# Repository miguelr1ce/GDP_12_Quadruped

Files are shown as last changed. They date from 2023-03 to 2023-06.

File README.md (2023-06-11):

# GDP_12_Quadruped
4th year group project for University of Southampton (2022/2023)

Title: Creating a Modular Quadrupedal Robot

Group Members:
1) Ryan Khoo Yeap Hong                     -> Lead Vibe Checker
2) Nirvair Kaur Jasbir Singh               -> Editor & Chief
3) Khor Chong Shen                         -> ODrive Whisperer
4) Miguel Antonio Alfonso Villarivera      -> The Cogfather
5) Jia Hao Gau                             -> Mr. Safety
6) Ka Wai Ken Chung                        -> Gait Keeper
 
 FULL FUSION360 CAD FILE: https://drive.google.com/file/d/1EFiVYnqyQNYSkIoPCi1z3-Mt8qbjOBQe/view?usp=sharing
 
 (open fusion and import file, will populate with all designs and dependencies)
 
 Some features of our quadrupedal robot
 1. 3DoF for each leg
 2. Modular leg detach, feet, body mounts
 3. Herringbone and worm wheel gear reduction
 4. Gait Generating GUI
 5. Bluetooth Controller
 
Mqrph

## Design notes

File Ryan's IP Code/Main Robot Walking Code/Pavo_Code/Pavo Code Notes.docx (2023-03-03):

# Pavo robot-side Code Information

Content of code OUTDATED:

1. Changeable and tuneable parameters
  - General actiaon execution speed
  - Empty footstep modifier
  - Start-up options (toggles initialisation or testing mode)
- Calibration for centres of servos
- Movement ranges, maximum degrees of movement for each joint
2. Movement sets
3. Not usually changed parameters and various other variable definitions
  - Servo Numbers
4. Predefined Functions and calculations
  - Servodriver Pulse calculations
  - executePosition function, Write position dataset to servos
5. assumePosition()
  - Misc setup
6. Setup
  - Serial begin at 9600 baudrate
  - Servodriver setup
7. Void Loop
  - check controller command data
  - Manual Pitch Control

## Walking set info

Final set to be written to servos is a combination of an empty set of sets, and the front back movements and left right movements are appended on to a degree determined by the fuzzy logic crisp output.

0.8 secs looks to be a good duration for a full walk cycle as of now

How do I make between different sets have different amount of divisions?

Divisions will occur at even intervals, so if I want a faster movement, I will divide a movement into fewer divisions that end up more spaced out

Sets in sets

If modifiers for x and y are below a certain preset threshold, pavo will resume neutral standing positin unmovingi.e. Pavo will automatically come to rest if it is balanced

Easing function Multipliers:

Linear:

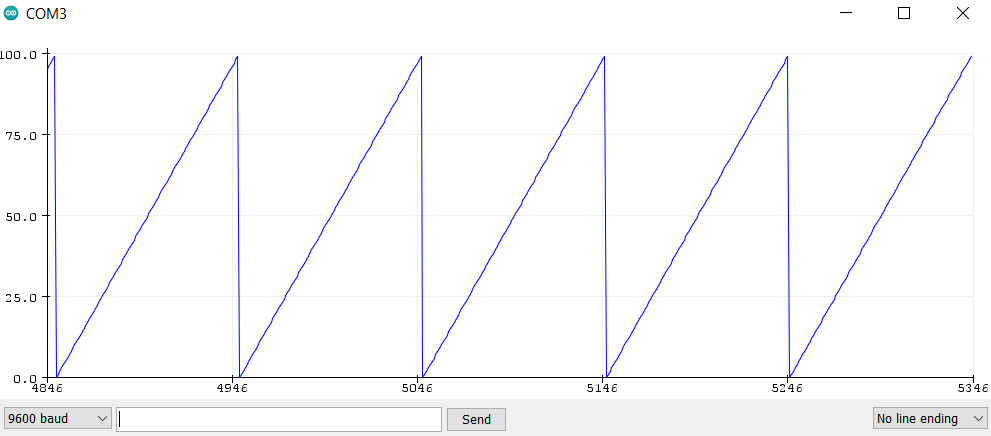
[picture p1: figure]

slow down:

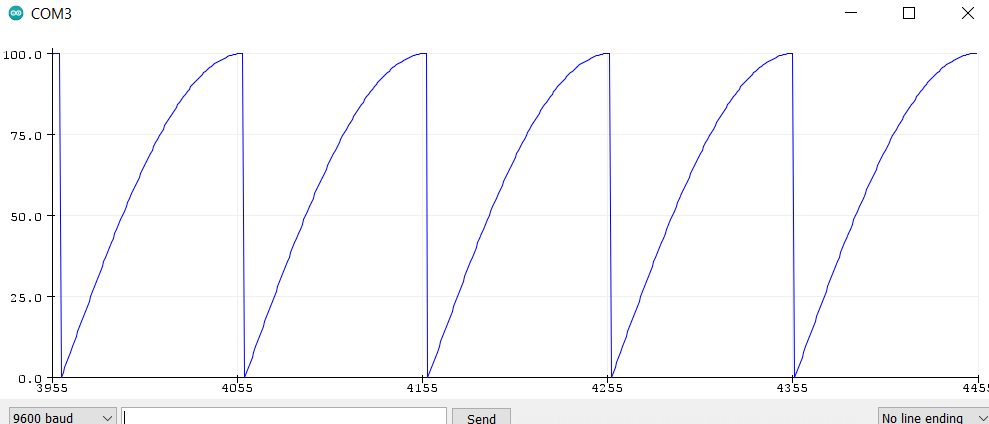
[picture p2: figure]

speed up:

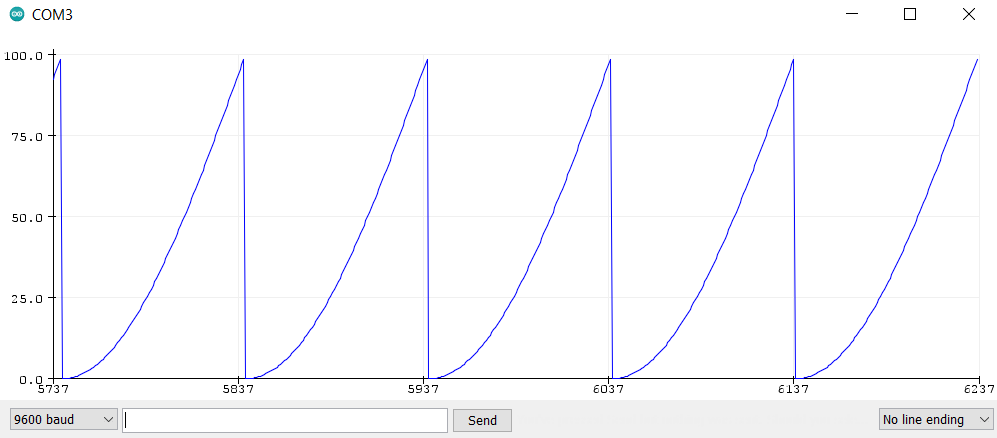
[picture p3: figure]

MEMORY MAXIMUM HAS BEEN REACHED

Due to the large size of sets that need to be processed and stored for footstep planning, the maximum divisions has been set to 18

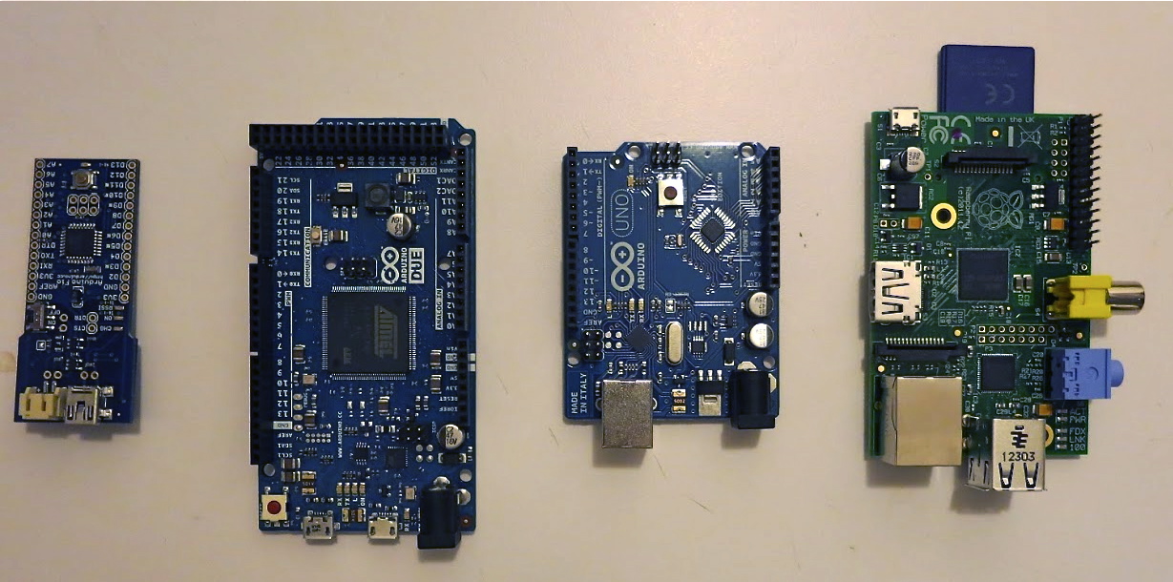
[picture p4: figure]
Arduino Uno and Due Size Comparison (with Raspberry Pi and Fio, too) — DO IT: Projects, Plans, and How-tos

The Due is not too much bigger

https://learn.adafruit.com/memories-of-an-arduino/optimizing-sram

Cycle Loop:

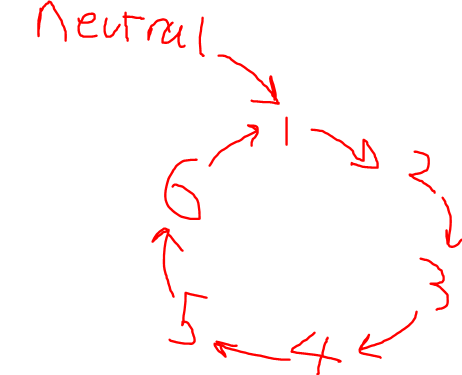
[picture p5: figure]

Old walking sets

//Temporary walking sets L L L R R R M M M t ---------------------------------------------------------------------

const int temp1ServoState[] = {-30, -10, 0, 80, 100, 0, 0, 0, 0, 15};

const int temp2ServoState[] = {-15, 30, 0, 10, 80, 0, 0, 0, 0, 15};

const int temp3ServoState[] = {-80, 40, 0, 10, 40, 0, 0, 0, 0, 15};

const int temp4ServoState[] = {-80, -100, 0, 30, 10, 0, 0, 0, 0, 15};

const int temp5ServoState[] = {-10, -80, 0, 15, -30, 0, 0, 0, 0, 15};

const int temp6ServoState[] = {-10, -40, 0, 80, -40, 0, 0, 0, 0, 15};

Exponential filter:

https://www.megunolink.com/documentation/arduino-libraries/exponential-filter/

explain the math ryan.

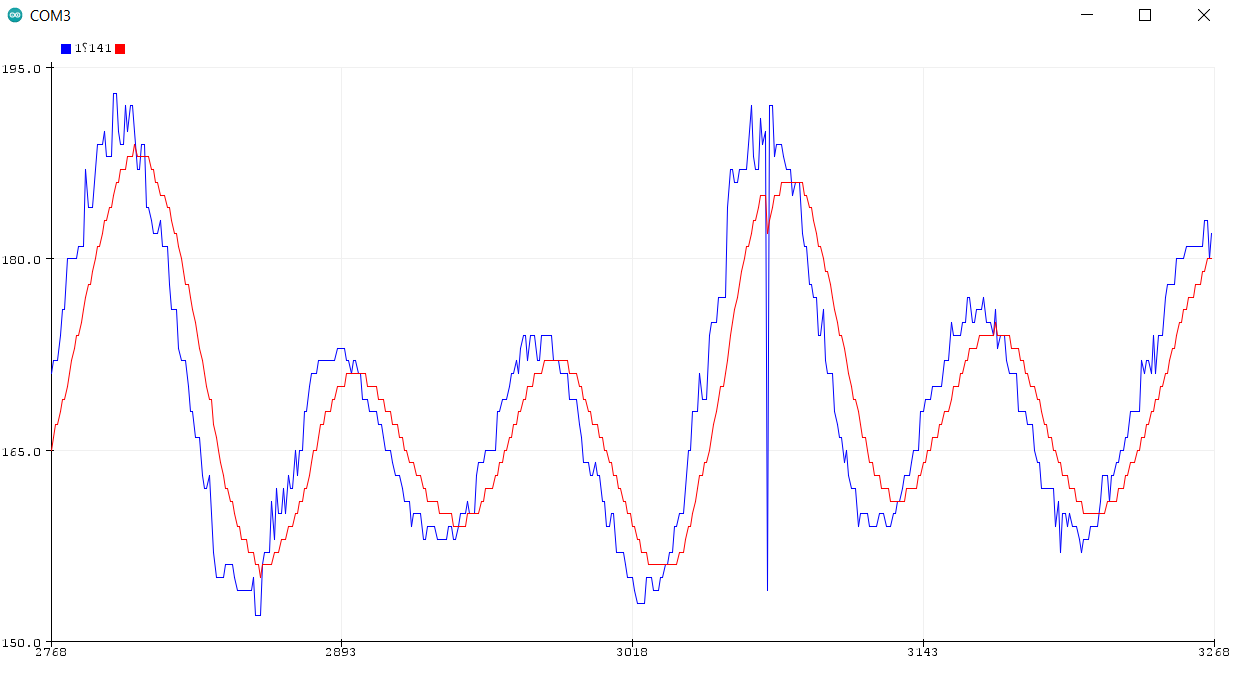
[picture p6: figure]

Calculate pitch and yaw n stuff from IMU

https://howtomechatronics.com/tutorials/arduino/arduino-and-mpu6050-accelerometer-and-gyroscope-tutorial/

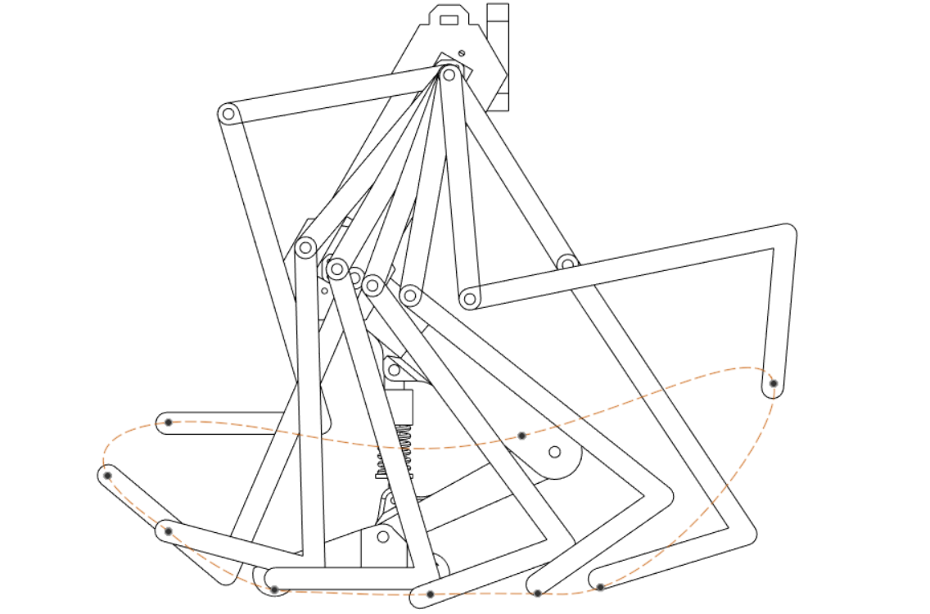
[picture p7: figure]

“air”

“air”

Contact 1 C2 C3 C4 C5 C6

6 stages are touching ground, 2 are in the air to facilitate the swing forward. The other leg follows the same cycle but is offset by 4 stages, allowing 2 states of ground contact to overlap, fulfilling the double contact state for a total of 26% of the cycle as in figure [bird walk]. It can be broken down into 6 states of ground contact and 2 states of mid-air swing, this is similar for the sideways movement, but is simpler, as the ground contact only requires the moving of the hip servos sideways at a regular speed until the swing phase that swings the leg back to a starting position.

The duration of ther stages can be altered in the code with the time variable attached to each of the sets, but with a single gait cycle broken down into 8 parts, each part comes to 100/8=1205% which is in line with the 13% recorded, this allows a low number of divisions with all the sets having the same duration.

If higher ram with more divisions possible, the time variable can be adjusted to allow the double support phases to come closer to 13% of the cycle.

This is a

https://edmond.mpdl.mpg.de/dataset.xhtml?persistentId=doi:10.17617/3.ETFG41

# PROGMEM implementation

Using https://github.com/Chris--A/PGMWrap to aid in storing sets in flash memory instead of SRAM to free up space:

Before implementation:

After:

Allows max divisions to go back up to above 10, allowing for smooth motion and the easing function to actually do things!!!

After this limiting factor is speed of loop execution, as of implementing the PROGMEM, a loop takes on average 0.011 seconds

# Leg planning puppeteering

Empty set was made representing the foot lift, and side to side swing manually tuned to reduce the hip wobbling, counteracting the legs causing the hip to swing back and forth

Footstep cycle: | % cycle | Empty | Front/back | Left/right
1 | 12.5% | Right leg up + spine counteract | L C3, R air | L C3, R air
1-2 | | - | R Swing + L walk | R Swing + L walk
2 | 12.5% | Right leg up + spine counteract | L C4, R air | L C4, R air
2-3 | | Right leg move down | L walk | L walk
3 | 12.5% | Neutral | L C5, R C1 | L C5, R C1
3-4 | | - | L and R walk, D support. | L and R walk, D support.
4 | 12.5% | Neutral | L C6, R C2 | L C6, R C2
4-5 | | Left leg move up | R walk | R walk
5 | 12.5% | Left leg up + spine counteract | L air, R C3 | L air, R C3
5-6 | | - | L Swing + R walk | L Swing + R walk
6 | 12.5% | Left leg up + spine counteract | L air, R C4 | L air, R C4
6-7 | | Left leg move down | R walk | R walk
7 | 12.5% | Neutral | L C1, R C5 | L C1, R C5
7-8 | | - | L + R walk, D support. | L + R walk, D support.
8 | 12.5% | Neutral | L C2, R C6 | L C2, R C6
8-1 | | Right leg move up | L walk | L walk

Departure from biomimicry,

Due to the low strength of the servos, the gait angles need to be smaller for the servos to be able to actuate to the target positions, and alos due to this reduced dynamic forces, the robot is unable to properly achive foot lift off during its swing phase, essentially maintaining double support throughout its entire gait cycle. With the servos implemented, it is able to shuffle along, but not fully walk like the cycle illustrates, despite while simply increasing the actuation modifiers, such as the angle of gait swings and sufficiently powerful servos would allow for walking as in the above diagram.

This shuffling is due the the compliance of the frame and joints of the robot, when a foot is raised, instead of the foot rising, the entire body will bend to accommodate this new positioning, this compliance is due to the weight of the hip and spine pressing down on the leg assemblies. This causes the overall robot to bend in ways tha3t would not be possible if all parts were rigid. This issue may be alleviated by increasing the motion of the joints, where the body is rigid enough to not allow angular compliance of larger angles, however, the servos are simply not strong enough achieve the torques necessary to perform these larger angled foot steps, regardless of sideways or forwards.

It is the combination of these two issues that limit each other that result in the robot not performing as initially intended. However, knowing this, work was still done to maximise the robot’s ability to maneuver under these new sets of constraints.

In light of this, modifications were made to improve performance in its current form (utilising constant double support. The percentage of time the legs are swinging back forward (supposedly mid-air under normal circumstances) have been reduced to half that of the other stages. With all other parameters the same, this increased walking speed by.

RYAN test to do: original planned motion based on real quail; improvements based on research platform.

SERVOS NOT STRONG ENOUGH TO WALK, CAN SHUFFLE THOUGH

The current movements are broken down into 3 sets that are combined with different weightages, future work may also use this now ealisy expandable framework to break down complex movement into further sub-catagories to further refine and improve control of the CPG. An example would be breaking down the empty set into separate footstep and counterbalance movements, and have the counterbalance be further informed by more IMU data to counteract more dynamic, unexpected perturbances such as potholes, inclined/slippery surfaces, etc.

This system that relies on higher functionality instead of taking into account all the math behind the dynamics, inverse kinematics, etc. not only saves computation but is also much more readily adaptable to new more challenging terrain, where a system whose movements are calculated based on assumptions such as 0-inclined surfaces, no slip, unrealistic perfectly rigid body parts may need to overhaul its entire calculations to take these new variables into account, this system may be altered by simply changing parameters or breaking down the step cycles into more parts as mentioned above.

Demonstration values, slow exaggerated movements.

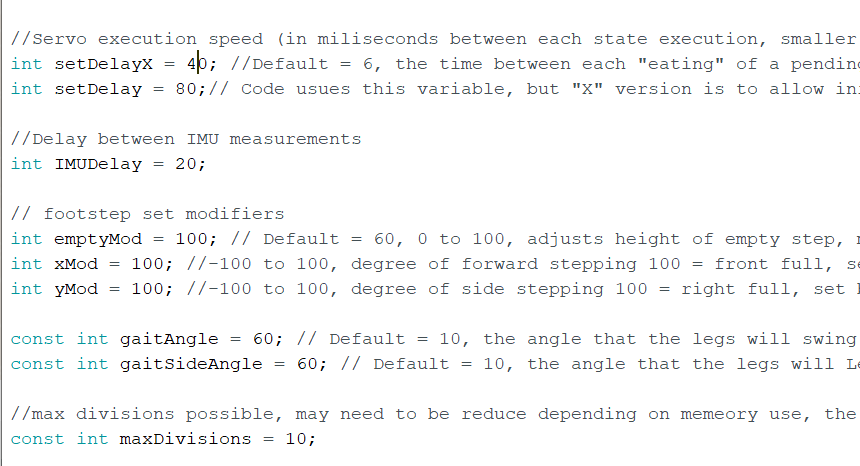
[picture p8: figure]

{50, 24, -20, 0, -64, -94, 5, 0, 14, 10}

Servo 8

Servo 7

Servo 4

Servo 5

Servo 2

Divisions

Servo 9

Servo 6

Servo 3

Servo 1

9

9

9

9

Gait Cycle Stages

Rest state

1

2

3

8

4

9

# Archived debugging code:

// //print pending set

// Serial.println("Pending set:");

// for ( int i = 0; i < maxDivisions+1 ; i++){

// Serial.print("Set indexed at ");

// Serial.print(i);

// Serial.print(": {");

// for ( int s = 0; s < 9 ; s++){

// Serial.print(pendingSet[i][s]);

// Serial.print(", ");

// }

// Serial.println("}");

// }

Goes just before end of respective servo loop in assumePosition():

// //printing temporary column

// Serial.print("tempcolumn[]");

// Serial.print(" for servo number ");

// Serial.print(servoNumber);

// Serial.print(": {");

// for ( int i = 0; i < divisions ; i++){

// Serial.print(tempColumn[i]);

// Serial.print(", ");

// }

// Serial.println("}");

// Serial.print("servo ");

// Serial.print(servoNumber);

// Serial.println("'s transition values calculated");

Goes below respective servo loop in assume position function

//// Printing transitionArray

//Serial.println("Transition array:");

//for (int s=0;s<9;s++){

// Serial.print("colunm array for servo ");

// Serial.print(s);

// Serial.print(": [");

// for (int i = 0; i < divisions ; i++){

// Serial.print(transitionArray[s][i]);

// Serial.print(", ");

// }

// Serial.println("] ");

//}

// //print out new set

// Serial.print("Old set overwritten to new set: ");

// for (int i=0; i<9; i++){

// Serial.print(newSet[i]);

// Serial.print(", ");

// }

// Serial.println(" ");

//Write transitionary array into the pending sets from the back

//Serial.println("Populating pending set:");

//write to pending sets from transition array, transposing matrix

for ( int i = 0; i < divisions ; i++){

for ( int s = 0; s < 9 ; s++){

pendingSet[divisions-i-1][s] = transitionArray[s][i];

//Serial.println(pendingSet[divisions-i-1][s]);

}

//Serial.print("one pending set added at index: ");

//Serial.println(divisions-i-1);

}

Nomenclature:

m | - | Mass
t | - | Time

Set value:

20

0

100

-100

True Servo angle:

159°

109°

134°

139°

Servo Centre - range

Servo Centre + range

Servo Centre

(Centre pre-set at 134°, allowable range pre-set at ±25°)

{{x, x, x, x, x, x, x, x, x, 0},

{x, x, x, x, x, x, x, x, x, 0},

{x, x, x, x, x, x, x, x, x, 0},

{x, x, x, x, x, x, x, x, x, 0},

{x, x, x, x, x, x, x, x, x, 0},

{x, x, x, x, x, x, x, x, x, 0},

{x, x, x, x, x, x, x, x, x, 0},

{x, x, x, x, x, x, x, x, x, 0},

{x, x, x, x, x, x, x, x, x, 0},

⋮

{x, x, x, x, x, x, x, x, x, 0},

⋮

{0, 0, 0, 0, 0, 0, 0, 0, 0, N}}

New position set

Transitionary position sets

Length dependant on maximum divisions allowed by pre-set variable in code

Current position set

Last set containing only “available sets” variable

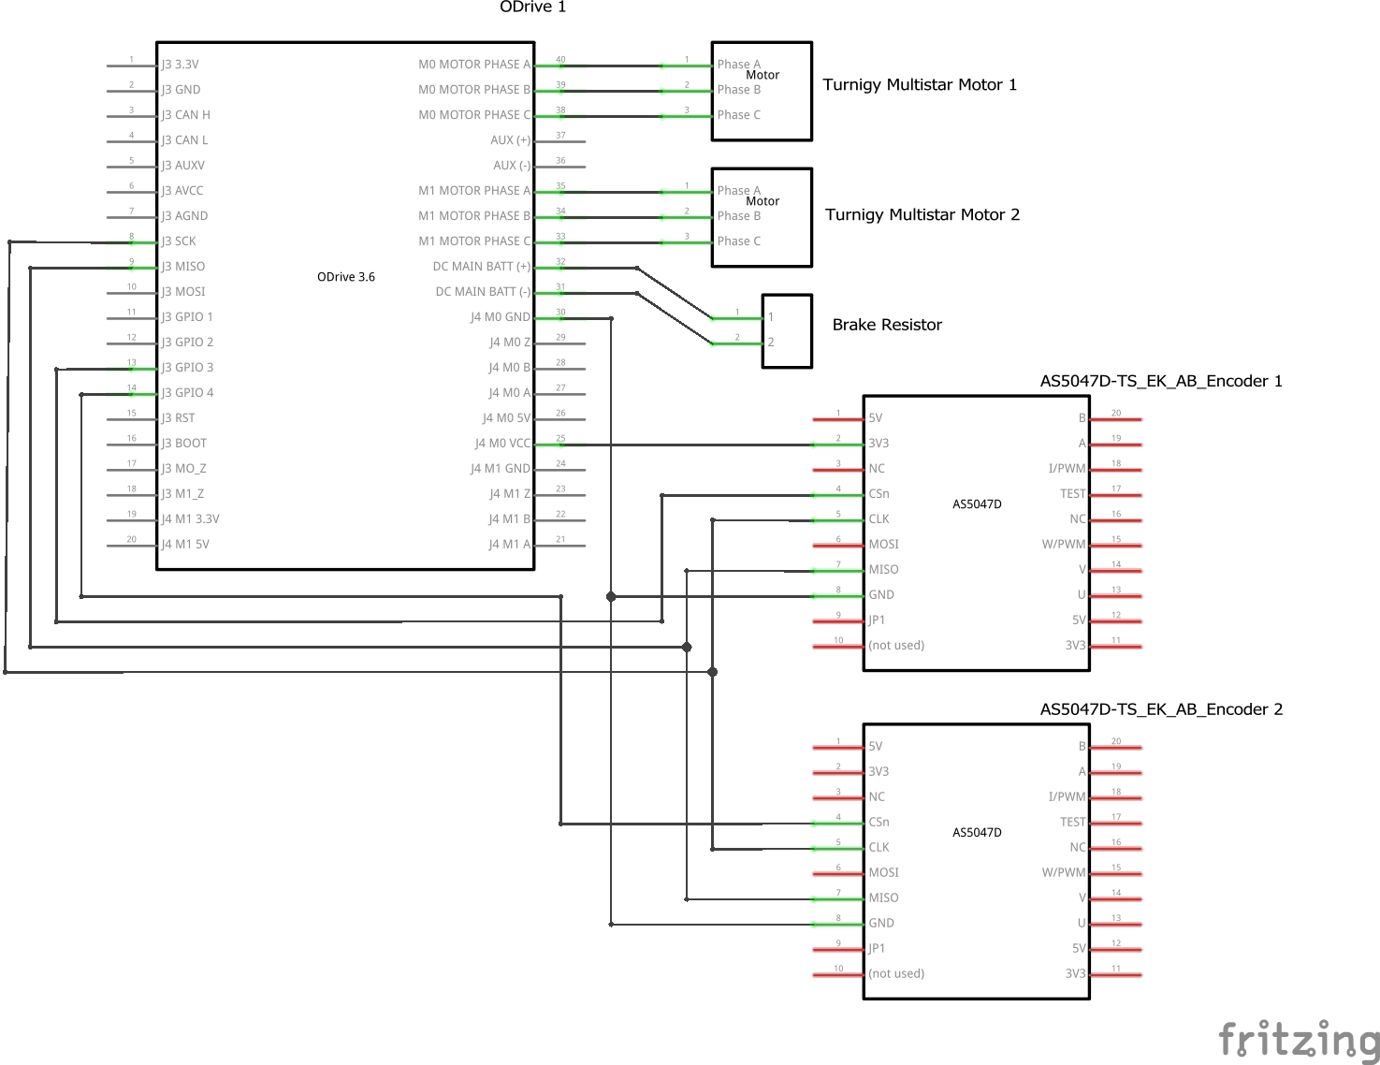
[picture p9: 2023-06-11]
Morph Designs/Circuit Diagrams/motor+encoder_schem.jpg

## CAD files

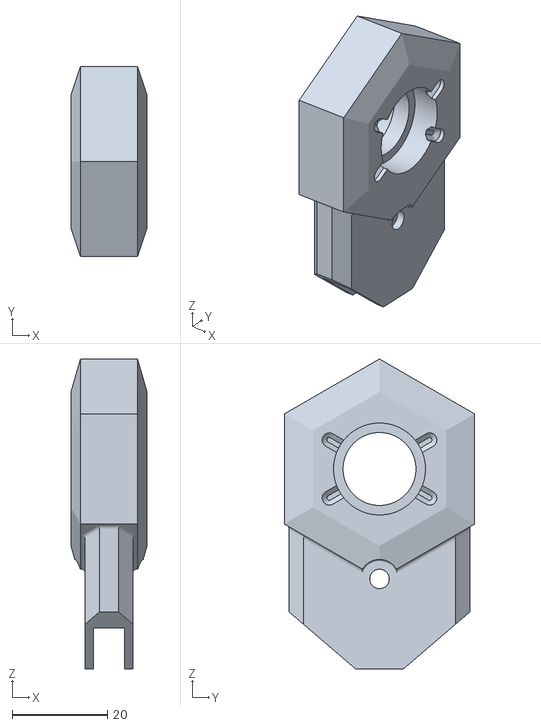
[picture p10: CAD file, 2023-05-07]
Morph Designs/Knee Joint/Main Knee Joint.stl
16.0 x 40.0 x 65.1

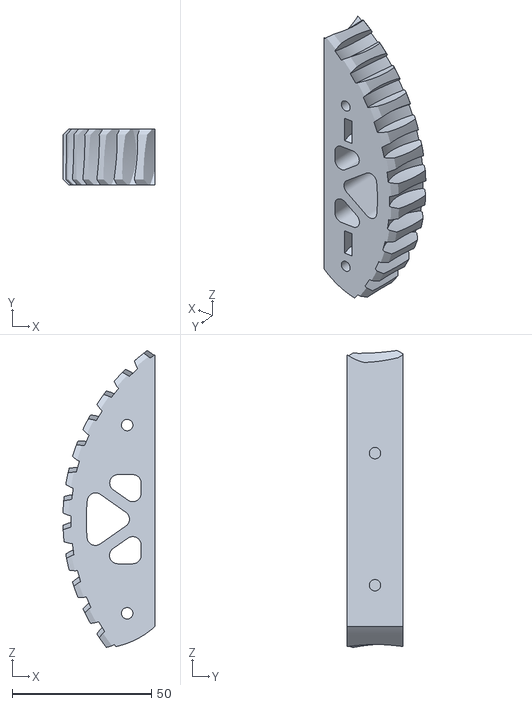
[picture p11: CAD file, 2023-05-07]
Morph Designs/Worm Gear assembly/Worm Wheel Main.stl
33.0 x 20.0 x 106.6

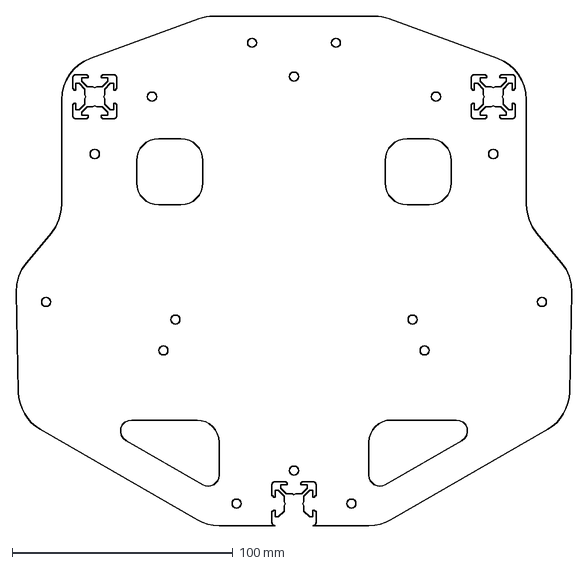
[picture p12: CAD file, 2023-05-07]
Morph Designs/Body/2X Middle Plate.dxf
252.0 x 230.9 mm

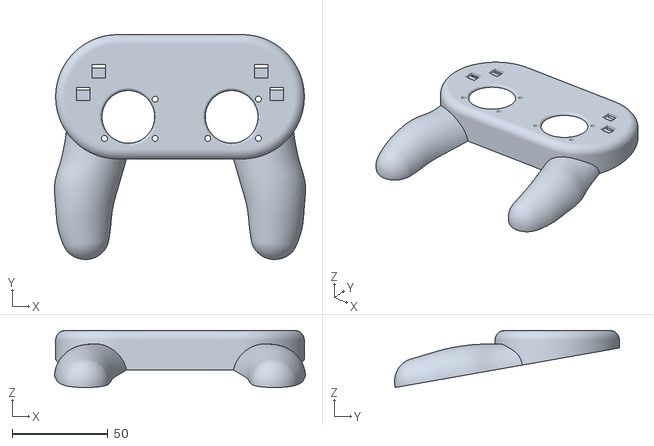
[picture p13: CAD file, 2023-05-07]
Morph Designs/Controller/Top Body.stl
131.2 x 117.5 x 29.8

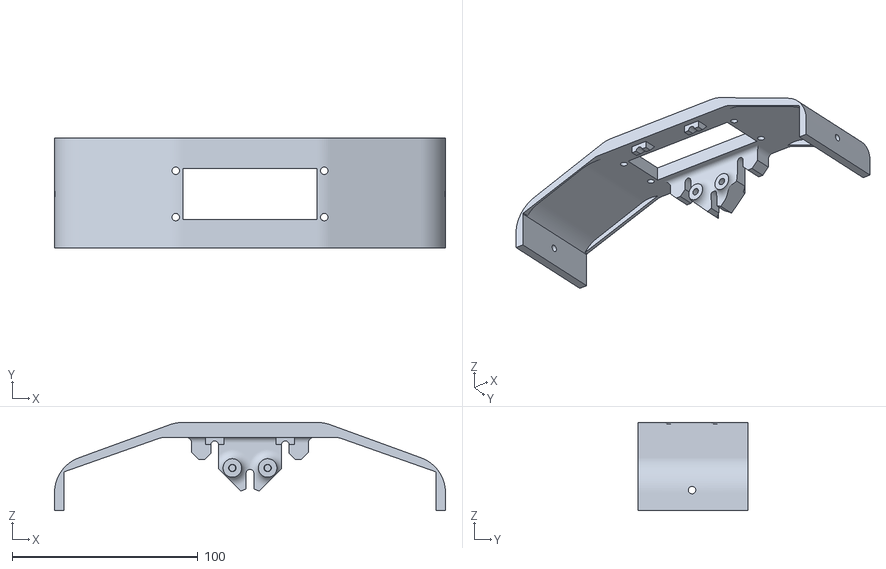
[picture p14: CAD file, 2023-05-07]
Morph Designs/Electronics housing/Electronics Housings v7.stl
210.6 x 59.2 x 47.5

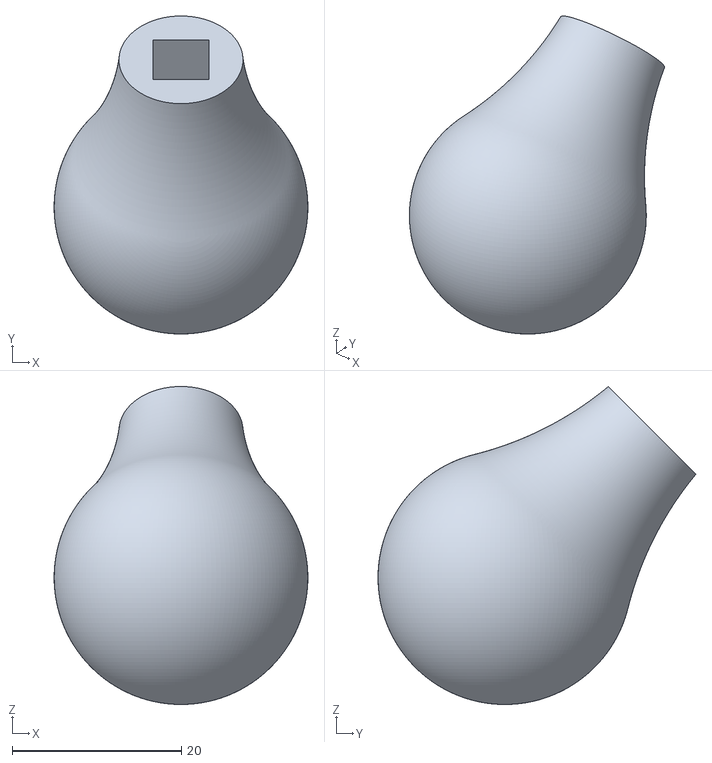
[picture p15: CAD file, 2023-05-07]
Morph Designs/Feet/Round Foot V2.stl
30.0 x 37.6 x 37.6

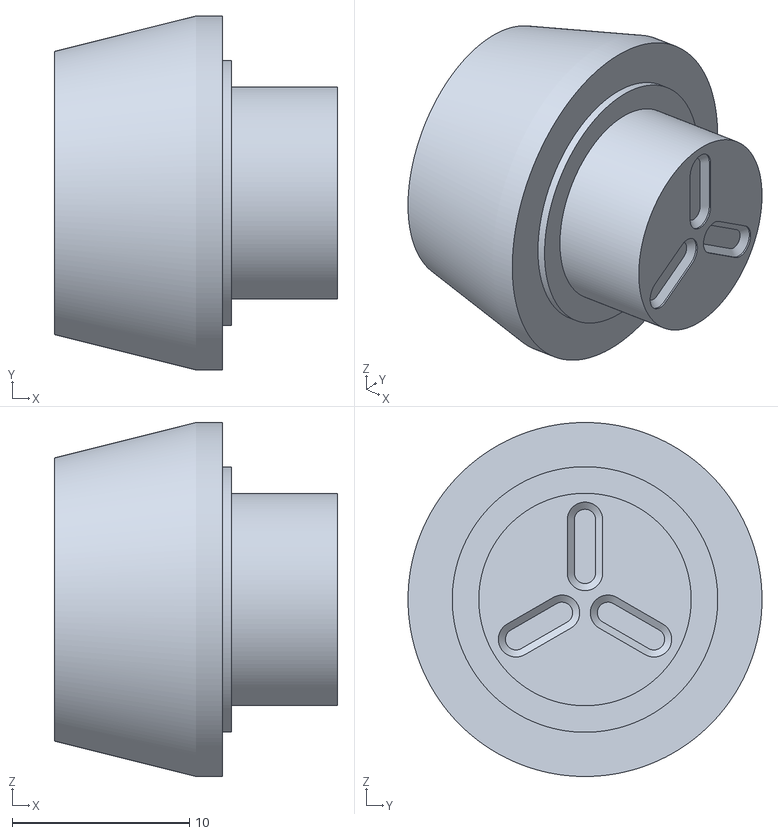
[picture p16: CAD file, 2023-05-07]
Morph Designs/Gear Assembly/Shaft Brace B.stl
16.0 x 20.0 x 20.0

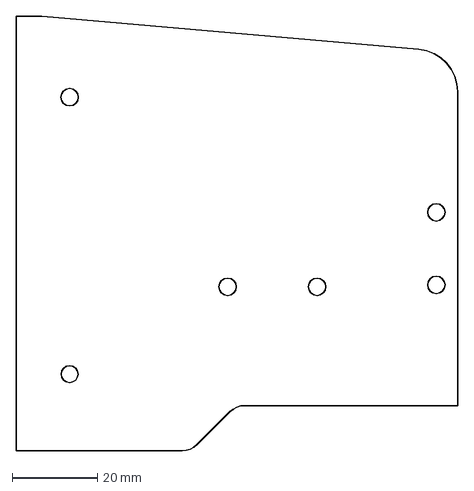
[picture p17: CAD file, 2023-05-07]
Morph Designs/Gear Box Assembly/Side Panel B.dxf
103.6 x 102.0 mm

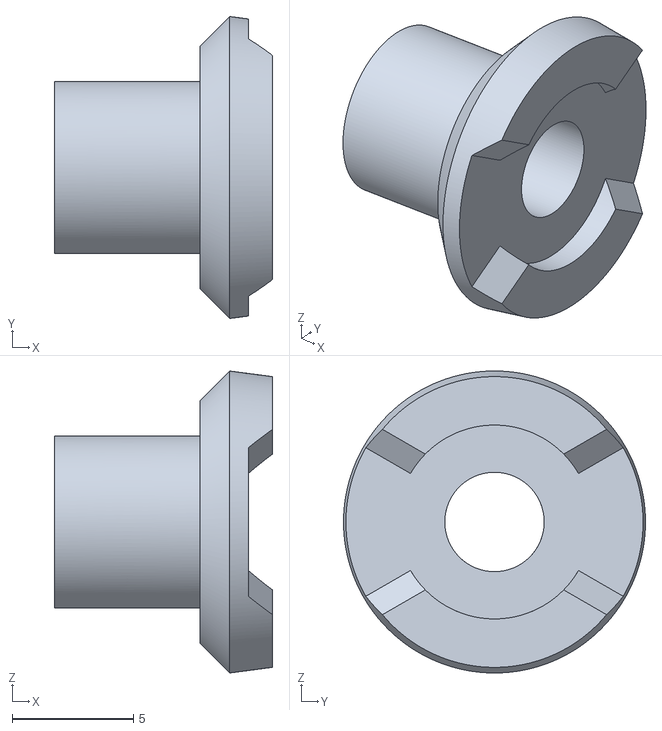
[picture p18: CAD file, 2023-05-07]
Morph Designs/Knee Joint/Gear Holder Outer.stl
9.00 x 12.5 x 12.5

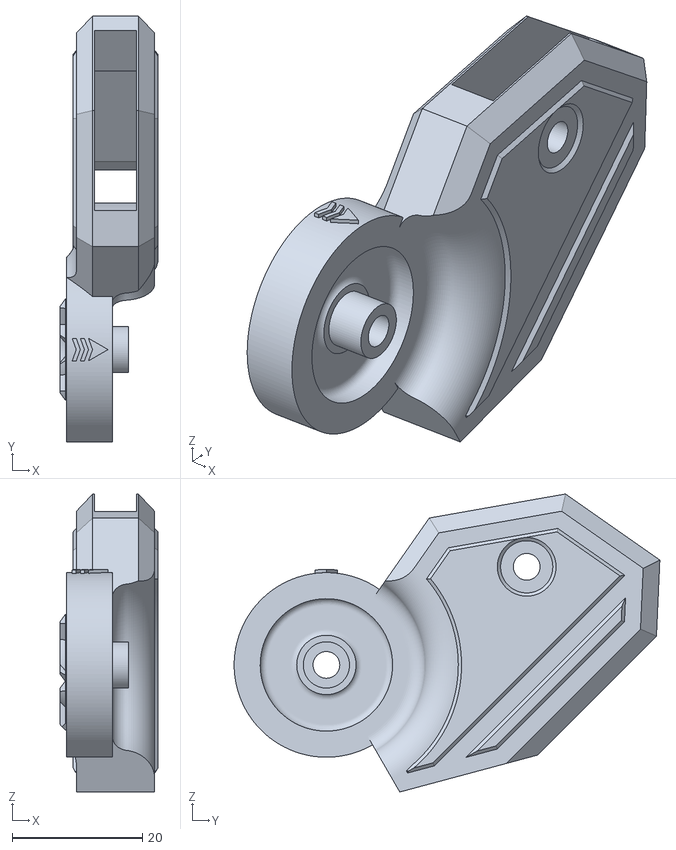
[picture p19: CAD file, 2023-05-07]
Morph Designs/Legs/Foot Joint 2.stl
15.0 x 65.3 x 45.7

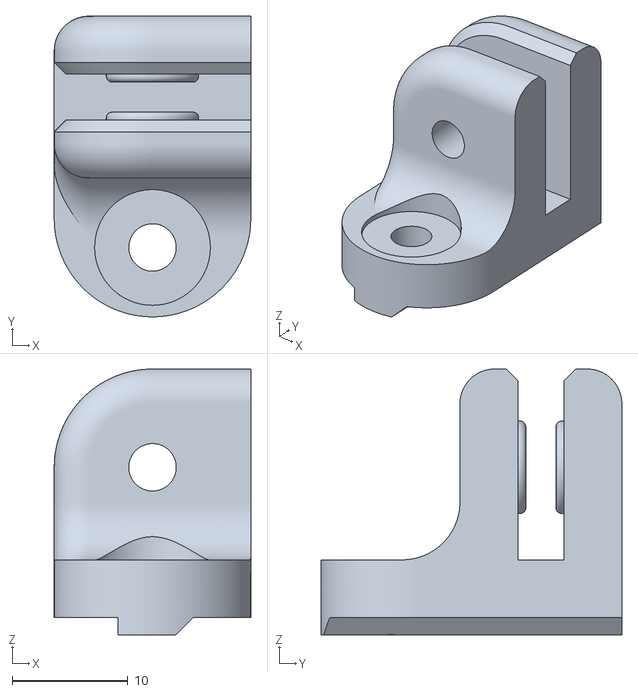
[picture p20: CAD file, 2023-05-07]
Morph Designs/Odrive Mounts/Odrive Mount V4.stl
17.0 x 26.0 x 23.0

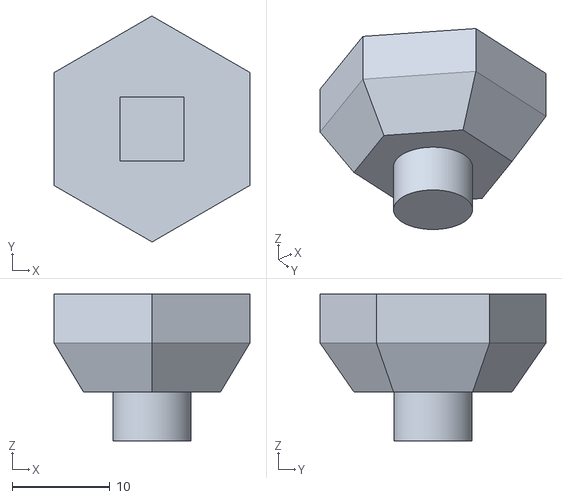
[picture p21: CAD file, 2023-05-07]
Morph Designs/Worm Gear assembly/Motor Shaft Brace'.stl
20.0 x 23.1 x 15.0

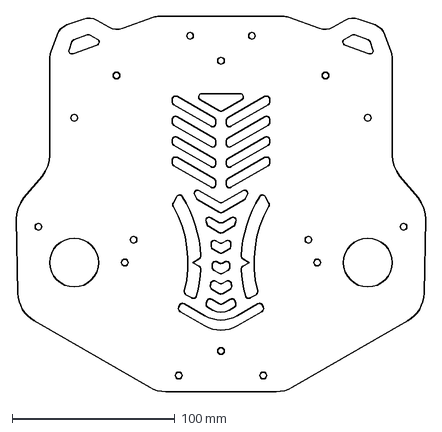
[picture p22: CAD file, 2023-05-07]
Morph Designs/Body/Face Plate Blank.dxf
252.0 x 230.9 mm

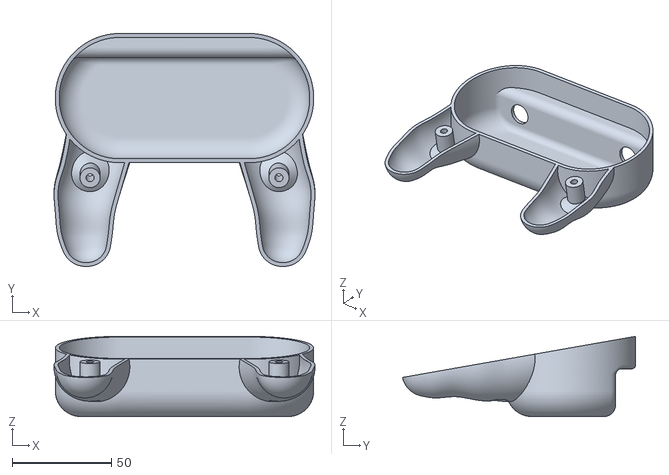
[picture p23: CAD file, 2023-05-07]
Morph Designs/Controller/Bottom.stl
131.3 x 117.2 x 40.4

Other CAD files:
Morph Designs/Electronics housing/Electronics board DXF.dxf
Morph Designs/Gear Assembly/2X Shaft Brace Bearing Mount.stl
Morph Designs/Gear Box Assembly/Back panel.dxf
Morph Designs/Knee Joint/Gear Holder Inner.stl
Morph Designs/Body/Aluminium Extrusion Braket.stl
Morph Designs/Body/Face Plate Logos.dxf
Morph Designs/Gear Assembly/Big Gear.stl
Morph Designs/Gear Assembly/Gear Spacer A V2.stl
Morph Designs/Gear Assembly/Gear Spacer B1.stl
Morph Designs/Gear Assembly/Gear Spacer B2.stl
Morph Designs/Gear Assembly/Gear Spacer C.stl
Morph Designs/Gear Assembly/Motor Shaft Mount A.stl
Morph Designs/Gear Assembly/Motor Shaft Mount B.stl
Morph Designs/Gear Assembly/Shaft Brace A.stl
Morph Designs/Gear Box Assembly/Acrylic Mount.stl
Morph Designs/Gear Box Assembly/Acrylic plate.dxf
Morph Designs/Gear Box Assembly/Bearing Clasp Top.stl
Morph Designs/Gear Box Assembly/Bearing clasp Bottom.stl
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

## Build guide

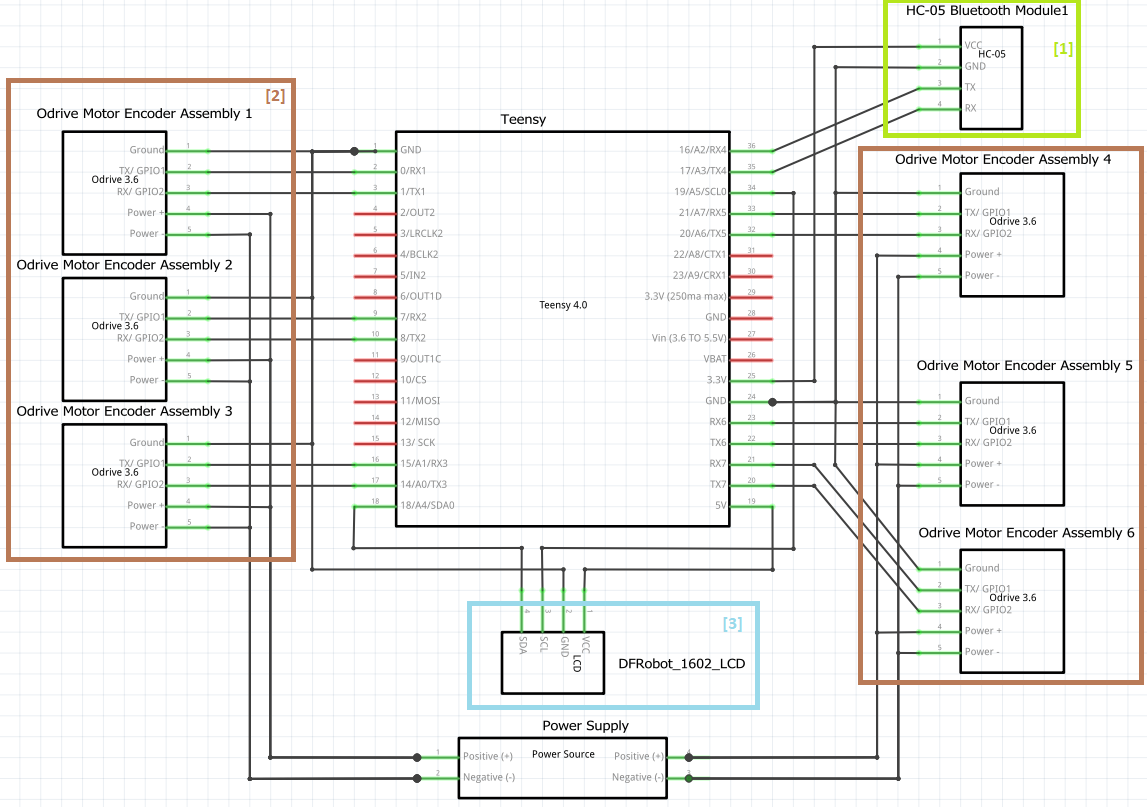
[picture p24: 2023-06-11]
Morph Designs/Circuit Diagrams/Teensy_assembly.png

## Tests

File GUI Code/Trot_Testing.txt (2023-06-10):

struct Trot_Testing{
    double March[itr][legn][coor]={{{0, 0, 0.0}, {0, 0, 0.0}, {0, 0, 0.0}, {0, 0, 0.0}}, {{0, 0, 50.0}, {0, 0, 50.0}, {0, 0, 0.0}, {0, 0, 0.0}}, {{0, 0, 50.0}, {0, 0, 50.0}, {0, 0, 0.0}, {0, 0, 0.0}}, {{0, 0, 50.0}, {0, 0, 50.0}, {0, 0, 0.0}, {0, 0, 0.0}}, {{0, 0, 0.0}, {0, 0, 0.0}, {0, 0, 0.0}, {0, 0, 0.0}}, {{0, 0, 0.0}, {0, 0, 0.0}, {0, 0, 50.0}, {0, 0, 50.0}}, {{0, 0, 0.0}, {0, 0, 0.0}, {0, 0, 50.0}, {0, 0, 50.0}}, {{0, 0, 0.0}, {0, 0, 0.0}, {0, 0, 50.0}, {0, 0, 50.0}}};
    double FB[itr][legn][coor]={{{0, -60.0, 0}, {0, -60.0, 0}, {0, 60.0, 0}, {0, 60.0, 0}}, {{0, -30.0, 0}, {0, -30.0, 0}, {0, 30.0, 0}, {0, 30.0, 0}}, {{0, 0.0, 0}, {0, 0.0, 0}, {0, 0.0, 0}, {0, 0.0, 0}}, {{0, 30.0, 0}, {0, 30.0, 0}, {0, -30.0, 0}, {0, -30.0, 0}}, {{0, 60.0, 0}, {0, 60.0, 0}, {0, -60.0, 0}, {0, -60.0, 0}}, {{0, 30.0, 0}, {0, 30.0, 0}, {0, -30.0, 0}, {0, -30.0, 0}}, {{0, 0.0, 0}, {0, 0.0, 0}, {0, 0.0, 0}, {0, 0.0, 0}}, {{0, -30.0, 0}, {0, -30.0, 0}, {0, 30.0, 0}, {0, 30.0, 0}}};
    double LR[itr][legn][coor]={{{-60.0, 0, 0}, {-60.0, 0, 0}, {60.0, 0, 0}, {60.0, 0, 0}}, {{-30.0, 0, 0}, {-30.0, 0, 0}, {30.0, 0, 0}, {30.0, 0, 0}}, {{0.0, 0, 0}, {0.0, 0, 0}, {0.0, 0, 0}, {0.0, 0, 0}}, {{30.0, 0, 0}, {30.0, 0, 0}, {-30.0, 0, 0}, {-30.0, 0, 0}}, {{60.0, 0, 0}, {60.0, 0, 0}, {-60.0, 0, 0}, {-60.0, 0, 0}}, {{30.0, 0, 0}, {30.0, 0, 0}, {-30.0, 0, 0}, {-30.0, 0, 0}}, {{0.0, 0, 0}, {0.0, 0, 0}, {0.0, 0, 0}, {0.0, 0, 0}}, {{-30.0, 0, 0}, {-30.0, 0, 0}, {30.0, 0, 0}, {30.0, 0, 0}}};
    double RT[itr][legn][coor]={{{-30.51, 18.68, 0}, {30.51, -18.68, 0}, {26.8, 23.69, 0}, {-26.8, -23.69, 0}}, {{-14.84, 10.01, 0}, {14.84, -10.01, 0}, {13.92, 11.26, 0}, {-13.92, -11.26, 0}}, {{0.0, 0.0, 0}, {0.0, 0.0, 0}, {0.0, 0.0, 0}, {0.0, 0.0, 0}}, {{13.92, -11.26, 0}, {-13.92, 11.26, 0}, {-14.84, -10.01, 0}, {14.84, 10.01, 0}}, {{26.8, -23.69, 0}, {-26.8, 23.69, 0}, {-30.51, -18.68, 0}, {30.51, 18.68, 0}}, {{13.92, -11.26, 0}, {-13.92, 11.26, 0}, {-14.84, -10.01, 0}, {14.84, 10.01, 0}}, {{0.0, 0.0, 0}, {0.0, 0.0, 0}, {0.0, 0.0, 0}, {0.0, 0.0, 0}}, {{-14.84, 10.01, 0}, {14.84, -10.01, 0}, {13.92, 11.26, 0}, {-13.92, -11.26, 0}}};
};

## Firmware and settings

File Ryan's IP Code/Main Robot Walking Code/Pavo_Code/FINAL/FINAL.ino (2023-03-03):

// Ryan Khoo Yeap Hong | 30480183 | Year 3 Individual Project | Academic year 2021/2022
#include <Wire.h>
#include <Adafruit_PWMServoDriver.h>
Adafruit_PWMServoDriver pwm = Adafruit_PWMServoDriver();
#include <Adafruit_ICM20948.h>
Adafruit_ICM20948 icm;
Adafruit_Sensor *icm_gyro, *icm_mag, *icm_accel;
#include <PGMWrap.h>
#include "Filter.h"

//Changable Parameters 0000000000000000000000000000000000000000000000000000000000000000000000000000000000000000000000000000000000000000000000000000000000000000000000000000000000000000000000000000000000000000

//Walking pattern progress tracked by:
int cycleStage ; 
int mode = 9; //<--<--<--<--<--<--<--<--<--<--<--<--<--<--<--<--<--<--<--<--<--<--<--<--<--<--<--<--<--<--<--<--<--<--<--<--<--<--<--<--<--<--
// 0 to disable all cycles (for debugging)
// 9 to begin in dynamic neutral
// 1 for normal operation
// 10 to enable servo initialisations 
// 20 for neutral position
// 30 for custom test position

//Servo execution speed (in miliseconds between each state execution, smaller number = faster execution)
int setDelayX = 2; //Default = 2, the time between each "eating" of a pending set, minimum depends on how fast void loop can execute
int setDelay = 2;// Code usues this variable, but "X" version is to allow initialisation to go slower before main loop

//Delay between IMU measurements
int IMUDelay = 20;

// footstep set modifiers
int emptyMod = 40; // Default = 40, 0 to 100, adjusts height of empty step, mostly unchanged.
int xMod = 0; //-100 to 100, degree of forward stepping 100 = front full, set by code
int yMod = 0; //-100 to 100, degree of side stepping 100 = right full, set by code

const int gaitAngle = 10; // Default = 20, the angle that the legs will swing forward and back, smaller angles require less torque, 50 for demo
const int gaitSideAngle = -10; // Default = 20, the angle that the legs will Left and Right, smaller angles require less torque, 50 for demo

//max divisions possible, may need to be reduce depending on memeory use, the higher the better/smoother.
const int maxDivisions = 10;

//when both X and Y modifiers are below stillThreshold, robot will stand still
int stillThreshold = 30;

//Modifier Weightages (100 = 1)
int fuzzWeight = 100;
int controllerWeight = 200;

//Filter Weights
ExponentialFilter<float > filteredRoll(5, 0);
ExponentialFilter<float> filteredPitch(5, 0);
ExponentialFilter<float > filteredAngVelX(5, 0);
ExponentialFilter<float > filteredAngVelY(8, 0);

//0000000000000000000000000000000000000000000000000000000000000000000000000000000000000000000000000000000000000000000000000000000000000000000000000000000000000000000000000000000000000000
//1111111111111111111111111111111111111111111111111111111111111111111111111111111111111111111111111111111111111111111111111111111111111111111111111111111111111111111111111111111111111111111111111
//Movement sets 
//Time Variable may be added in the tenth slot [9], values are in divisions. i.e. a value of 10 would mean 10 divisions between the previous state and the new input set, 
//more divisions = slower, time to assume new state in microseconds: t = divisions * setDelay

//Initialisation sets ------------------------------------------------------------------------------
const int16_p PROGMEM startServoState[]   = {0,0,0,0,0,0,0,0,0,1}; // Intant recenter, To neutral position at max speed CURRENTLY UNUSED
const int16_p PROGMEM neutralServoState[] = {0,0,0,0,0,0,0,0,0,10};// Servos centered, with last variable the time variable
const int16_p PROGMEM maxServoState[]     = {100,60,100,100,60,100,0,0,0,10};// Servos at full maximums
const int16_p PROGMEM minServoState[]     = {-100,-100,-50,-100,-100,-50,0,0,0,10};// Servos at full miniimums
//Test Leg state 
const int16_p PROGMEM testServoState[] = {0,0,100,0,0,100,0,0,0,6};// ONLY for testing

//Empty walking sets, defines time variable, other sets time value = 0 ----------------------------------------------------------------------------------
// int emptyMod = 100 This is above in changable states, adjusts height of step
//Only empty sets have a time value to differentiate durations of various stages
//                                          L    L   L   R    R   R   M   M   M   t
const int16_p PROGMEM empty1ServoState[] = {0,   0,  0, -50, -40, 0, -20, 0, 20,  4}; // retracted right leg
const int16_p PROGMEM empty2ServoState[] = {0,   0,  0, -50, -40, 0, -10, 0, 20,  4};
const int16_p PROGMEM empty3ServoState[] = {0,   0,  0,  0,   0,  0,  0,  0,  0,  6};
const int16_p PROGMEM empty4ServoState[] = {0,   0,  0,  0,   0,  0,  0,  0,  0,  6};
const int16_p PROGMEM empty5ServoState[] = {-50,-40, 0,  0,   0,  0, 20,  0, -20, 4}; //retracted left leg
const int16_p PROGMEM empty6ServoState[] = {-50,-40, 0,  0,   0,  0, 10,  0, -20, 4};
const int16_p PROGMEM empty7ServoState[] = {0,   0,  0,  0,   0,  0,  0,  0,  0,  6};
const int16_p PROGMEM empty8ServoState[] = {0,   0,  0,  0,   0,  0,  0,  0,  0,  6};
//Front-back walking sets ------------------------------------------------------------------------------------------------------------------------------
const int GD = gaitAngle/10; //GD = Gait division
const int16_p PROGMEM x1ServoState[] = {0,GD*-1,0,0,GD*5,0,0,0,0,0};
const int16_p PROGMEM x2ServoState[] = {0, GD*1,0,0,GD*-5,0,60,0,0,0};
const int16_p PROGMEM x3ServoState[] = {0, GD*3,0,0,GD*-5,0,30,0,0,0};
const int16_p PROGMEM x4ServoState[] = {0, GD*5,0,0,GD*-3,0,0,0,0,0};
const int16_p PROGMEM x5ServoState[] = {0, GD*5,0,0,GD*-1,0,0,0,0,0};
const int16_p PROGMEM x6ServoState[] = {0,GD*-5,0,0,GD*1,0,-60,0,0,0};
const int16_p PROGMEM x7ServoState[] = {0,GD*-5,0,0,GD*3,0,-30,0,0,0};
const int16_p PROGMEM x8ServoState[] = {0,GD*-3,0,0,GD*5,0,0,0,0,0};
//Left-right walking sets ------------------------------------------------------------------------------------------------------------------------------

const int GSD = gaitSideAngle/10; //GD = Gait side division, simmilar to above
const int16_p PROGMEM y1ServoState[] = {0,0,GSD*-1,0,0,GSD*-5,0,0,0,0};
const int16_p PROGMEM y2ServoState[] = {0,0,GSD*1,0,0,GSD*5,0,0,0,0};
const int16_p PROGMEM y3ServoState[] = {0,0,GSD*3,0,0,GSD*5,0,0,0,0};
const int16_p PROGMEM y4ServoState[] = {0,0,GSD*5,0,0,GSD*3,0,0,0,0};
const int16_p PROGMEM y5ServoState[] = {0,0,GSD*5,0,0,GSD*1,0,0,0,0};
const int16_p PROGMEM y6ServoState[] = {0,0,GSD*-5,0,0,GSD*-1,0,0,0,0};
const int16_p PROGMEM y7ServoState[] = {0,0,GSD*-5,0,0,GSD*-3,0,0,0,0};
const int16_p PROGMEM y8ServoState[] = {0,0,GSD*-3,0,0,GSD*-5,0,0,0,0};
// -----------------------------------------------------------------------------------------------------------------------------------------------------
//1111111111111111111111111111111111111111111111111111111111111111111111111111111111111111111111111111111111111111111111111111111111111111111111111111111111111111111111111111111111111111111111111111111111111111111111111111111111111
// Constant parameters and various other variable definitions 22222222222222222222222222222222222222222222222222222222222222222222222222222222222222222222222222222222222222222222222222222222222222222222222222222222222222222222

//Servo Numbers --------------------------------------------------------------------------------------------------------------------------------------------------------------------
const int16_p PROGMEM  LKneeServo = 0;
const int16_p PROGMEM  LHipServo = 1;
const int16_p PROGMEM  LHipSideServo = 2;
const int16_p PROGMEM  RKneeServo = 15;
const int16_p PROGMEM  RHipServo = 14;
const int16_p PROGMEM  RHipSideServo = 13;
const int16_p PROGMEM  lookServo = 4;
const int16_p PROGMEM  pitchServo = 5;
const int16_p PROGMEM  rollServo = 6;
//the above in a set for utilisations in fucntions:
const int servoSet[] = {LKneeServo, LHipServo, LHipSideServo, RKneeServo, RHipServo, RHipSideServo, lookServo, pitchServo, rollServo};

//Calibration for centers of servos, i.e. neutral angular positions,  ----------------------------------------------------------------------------------------------------------------
const int16_p PROGMEM  LKneeCenter = 100; //clockwise looking left
const int16_p PROGMEM  LHipCenter = 88+2;
const int16_p PROGMEM  LHipSideCenter = 90; //lowet, inner leg
const int16_p PROGMEM  RKneeCenter = 165; //counterclockwise looking left
const int16_p PROGMEM  RHipCenter = 90-2;
const int16_p PROGMEM  RHipSideCenter = 85;//Higher, leg goes towards center line
const int16_p PROGMEM  lookCenter = 93;//lower look right
const int16_p PROGMEM  pitchCenter = 88;//lower for higher head
const int16_p PROGMEM  rollCenter = 95;
//the above in a set for utilisations in fucntions:
const int servoCenter[] = { LKneeCenter, LHipCenter, LHipSideCenter, RKneeCenter, RHipCenter, RHipSideCenter, lookCenter, pitchCenter, rollCenter};// Servo centers in a set

//Movement ranges, maximum degrees of movement for each joint ---------------------------------------------------------------------------------------------------------------------
const int16_p PROGMEM  LKneeRange = 50;//range of degrees of Left Knee servo is +-60
const int16_p PROGMEM  LHipRange = 50;
const int16_p PROGMEM  LHipSideRange = 40;
const int16_p PROGMEM  RKneeRange = -50;
const int16_p PROGMEM  RHipRange = -50;
const int16_p PROGMEM  RHipSideRange = -40;
const int16_p PROGMEM  lookRange = 30;
const int16_p PROGMEM  pitchRange = 30;
const int16_p PROGMEM  rollRange = 35;
//the above in a set for utilisations in fucntions:
const int servoRange[] = {LKneeRange, LHipRange, LHipSideRange, RKneeRange, RHipRange, RHipSideRange, lookRange, pitchRange, rollRange};// Servo ranges in a set

//initial command state sent over bluetooth
int state = 0;

//needed for delayed set execution loop below
int timeOfLastLoop = 0;
//needed for delayed IMU measurement loop below
int timeOfLastIMU = 0;
float accAngleX, accAngleY, gyroAngleX, gyroAngleY, gyroAngleZ, yaw, roll, pitch;
  float GyroX;
  float GyroY;
//needed for delayed ultrasonic measurement loop below, in microseconds
int updateDistance = 0; //is set to 1 when distance needs to be updated.
int timeOfLastUltra = 0;
int ultraState = 0; //controls if the ultrasonic sensor is resting or pulsing for 10 microseconds.
int distanceSensed; //global variable storing distance of obastacle sensend by ultrasonic sensor, updates every 20 microseconds.

//temporary memory of its current position, for calculation of eased servo movement to the new state
int oldSet[] = {0,0,0,0,0,0,0,0,0,1}; //old set starts with neutral positions

//the "plate" of sets the code will need to "eat" one by one in the loop every setDelay amount of time.
int pendingSet[maxDivisions+1][9];
  //pendingSet[maxDivisions][9] = 0; // This line is in setup, the maxdivisions value in the set states how many "edible" sets are currently being stored and can be "eaten"

//Set that generate step writes to
int generatedSet[10];

//variable to allow neutral position to be executed only once upon entering neutral position
int enterNeutral = 1;
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
void loop() {

//Serial.print("cycleStage: "); Serial.print(cycleStage); Serial.print(", xMod:"); Serial.print(xMod); Serial.print(", yMod:"); Serial.println(yMod); 

  //Serial.println();
  //check controller command data  
  //Read Command
 if(Serial.available() > 0){ // Checks whether data is coming from the serial port
    state = Serial.read(); // Reads the data from the serial port
    //Serial.print("Bluetooth: "); Serial.println(state);
 }
 
    int currentTime = millis();
  //int timeOfLastIMU = 0; this line is in section 222222

  //Start of ultrasonic sensor -----------------------------------------------------------------
  if (updateDistance == 1){
  int microsecs = micros(); //micros utilised to avoid using delayMicroseconds()
  int timeSinceLastUltra = microsecs - timeOfLastUltra;
  if (timeSinceLastUltra >= 10){ //this if function runs every 10 microseconds
    if (ultraState == 0){ //turn on pulse
      digitalWrite(10, HIGH);
      ultraState = 1;
    }
    if (ultraState == 1){ //turns off pulse and records duration, returns distance
      digitalWrite(10, LOW );
      int duration = pulseIn(11, HIGH);
      distanceSensed = duration * 0.034 / 2;
      //Serial.println(distanceSensed);
      ultraState = 0;
    }
  }
  updateDistance = 0;
  } //End of ultrasonic sensor -----------------------------------------------------------------
  
  
  //Start of IMU *************************************************************************************************************************************************************************
  int timeSinceLastIMU = currentTime - timeOfLastIMU;
  if (timeSinceLastIMU > IMUDelay - 1 ){ // Start of delayed IMU loop, be=ased on IMU delay
  //Obtain updated IMU readings
  sensors_event_t gyro;
  sensors_event_t mag;
  sensors_event_t accel;
  icm_gyro->getEvent(&gyro);
  icm_mag->getEvent(&mag);
  icm_accel->getEvent(&accel);

  float AccX = accel.acceleration.x; 
  float AccY = accel.acceleration.y;
  float AccZ = accel.acceleration.z;
  float MagX = mag.magnetic.x;
  float MagY = mag.magnetic.y;
  float MagZ = mag.magnetic.z;
  GyroX = (gyro.gyro.x *57.3) +1.45;// convert to Deg/s, account for error. 1.45, these 2 are declared above
  GyroY = (gyro.gyro.y *57.3) -0.19;
  float GyroZ = (gyro.gyro.z *57.3) ;
  // float roll, pitch; in variables

  //Calculate position from acceleraometer data
  accAngleX = (atan(AccY / sqrt(pow(AccX, 2) + pow(AccZ, 2))) * 180 / PI) +2.4; //error of 2.4
  accAngleY = (atan(-1 * AccX / sqrt(pow(AccY, 2) + pow(AccZ, 2))) * 180 / PI) -2.4; 

  //Calculate position from Gyro data
  float elapsedTime = (timeSinceLastIMU / 1000.0);
  
  gyroAngleX = gyroAngleX + GyroX * elapsedTime; // deg/s * s = deg
  gyroAngleY = gyroAngleY + GyroY * elapsedTime;
  yaw =  yaw + GyroZ * elapsedTime;

  //Combine data for more accurate positiining w/out drift
  pitch = 0.96 * gyroAngleX + 0.04 * accAngleX;
  roll = 0.96 * gyroAngleY + 0.04 * accAngleY;

  //Serial print X and Y positioning
  //Serial.print(pitch);Serial.print(", ");
//  Serial.print(roll);
//  Serial.println();

    timeOfLastIMU = currentTime;
  }//end of delayed IMU loop ----------------------------------------

//end of IMU *************************************************************************************************************************************************************************

//Produce Direction Information, Xmod and Ymod based on 3 inputs: ultrasonic sensor data, IMU/fuzzy logic, and control info %%%%%%%%%%%%%%%%%%%%%%%%%%%%%%%%%%%%%%%%%%%%%%%%%%%%%%%%%%%%%%%%

//First, map IMU outputs to fuzzy logic Crisp inputs.
//Filter IMU data to avoid spikes/bumpiness from walking
filteredPitch.Filter(pitch); //angle varies +-20
filteredRoll.Filter(roll); //angle varies +-20
filteredAngVelX.Filter(GyroX); // +-100
filteredAngVelY.Filter(GyroY); // +-100

//Map extremes of value into fuzzy logic crisp input table, update depending on size of lookup table
int crispAngX = map(filteredPitch.Current() , -20,20,0,51);
int crispAngY = map(filteredRoll.Current() , -20,20,0,51);
int crispAngVelX = map(filteredAngVelX.Current() , -100,100,0,51);
int crispAngVelY = map(filteredAngVelY.Current() , -100,100,0,51);

//  Serial.print(GyroY);Serial.print(", ");
//  Serial.print(filteredAngVelY.Current());
//  Serial.println();

//extract data from look-up table to get fuzzXmod and fuzzYmod
int fuzzXmod;
int fuzzYmod;
if(crispAngX < 50 && crispAngX > 0 && crispAngY < 50 && crispAngY > 0 && crispAngVelX < 50 && crispAngVelX > 0 && crispAngVelY < 50 && crispAngVelY > 0 ){ //if statment to ensure values are within the bounds of lookuptable and does not extract random data from ram
fuzzXmod = fuzzTable[crispAngX][crispAngVelX];
fuzzYmod = fuzzTable[crispAngY][crispAngVelY];
}

//extract data from ultrasonic sensor
int obstacleMod;
if (distanceSensed < 20){
  obstacleMod = -20 ; //if less than 20cm, nudge backwards
}
if (distanceSensed >= 20){
  obstacleMod = 0 ; 
}

//extract data from remote controller
int controllerModX = 0;
int controllerModY = 0;
int controllerModXA = 0;
int controllerModXB = 0;
int controllerModYA = 0;
int controllerModYB = 0;
if (state >= 10 && state <= 19){ //front
  int frontState = state - 10;
    controllerModXA = frontState*3; //adds a maximum nudge of 30 to mod
 }
if (state >= 50 && state <= 59){ //back
  int backState = state - 50;
    controllerModXB = -backState*3; //adds a maximum nudge of -30 to mod
 }
if (state >= 30 && state <= 39){ //right
  int rightState = state - 30;
    controllerModYA = rightState*3; //adds a maximum nudge of 30 to mod
 }
if (state >= 70 && state <= 79){ //left
  int leftState = state - 70;
    controllerModYB = -leftState*3; //adds a maximum nudge of -30 to mod
 }
 controllerModX = controllerModXA + controllerModXB;
 controllerModY = controllerModYA + controllerModYB;
 


//Serial.print("ControllerModX: ");Serial.print(controllerModX);Serial.print(" ControllerModY: ");Serial.println(controllerModY);

//combine modifiers according to predetermined weights

xMod = (fuzzXmod*fuzzWeight*1 + controllerModX*controllerWeight + obstacleMod*100)/100;
yMod = (fuzzYmod*fuzzWeight*1 + controllerModY*controllerWeight)/100;

//Xmod and Ymod found %%%%%%%%%%%%%%%%%%%%%%%%%%%%%%%%%%%%%%%%%%%%%%%%%%%%%%%%%%%%%%%%%%%%%%%%%%%%%%%%%%%%%%%%%%%%%%%%%%%%%%%%%%%%%%%%%%%%%%%%%%%%%%%%%%%%%%%%%%%%%%%%%%%%%%%%%%%%%%%%%%%%%%%%%%%%


// Stand at neutral:
  if (cycleStage == 20 && pendingSet[maxDivisions][8] == 0){
    if (enterNeutral == 1){
    //extract set from PROGMEM into buffer set
    int bufferSet[10];
  for (int i=0; i<10; i++){ bufferSet[i] = startServoState[i]; }
    assumePosition(bufferSet, 0);
    enterNeutral = 0;
    }
  }
// Test State position:
  if (cycleStage == 30 && pendingSet[maxDivisions][8] == 0){
    
    //extract set from PROGMEM into buffer set
    int bufferSet[10];
  for (int i=0; i<10; i++){ bufferSet[i] = testServoState[i]; }
  
    assumePosition(bufferSet, 0);
  }

////first time initialisation loop ----------------------------------------------------------------------
//int cycleStage == 10 this is in changeable variables
  if (cycleStage == 10 && pendingSet[maxDivisions][8] == 0){
    //extract set from PROGMEM into buffer set
    int bufferSet[10];
  for (int i=0; i<10; i++){ bufferSet[i] = minServoState[i]; }
    assumePosition(bufferSet, 2);
    cycleStage = 11;
  }
  if (cycleStage == 11 && pendingSet[maxDivisions][8] == 0){
//extract set from PROGMEM into buffer set
    int bufferSet[10];
  for (int i=0; i<10; i++){ bufferSet[i] = maxServoState[i]; }  
    assumePosition(bufferSet, 0);
    cycleStage = 12;
  }
  if (cycleStage == 12 && pendingSet[maxDivisions][8] == 0){
//extract set from PROGMEM into buffer set
    int bufferSet[10];
  for (int i=0; i<10; i++){ bufferSet[i] = neutralServoState[i]; } 
    assumePosition(bufferSet, 1);
    cycleStage = 1; // Primes cycle stage to begin
  }
////end of first time initialisation --------------------------------------------------------------------


//555555555555555555555555555555555555555555555555555555555555555555555555555555555555555555555555555555555555555555555555555555555555555555555555555555555555555555555555555555555555555555555555555555555555555555555555555555555555555555555555555555555555555555555555555555555555555555555
//66666666666666666666666666666666666666666666666666666666666666666666666666666666666666666666666666666666666666666666666666666666666666666666666666666666666666666666666666666666666666666666666666666666666666666666666666666666666666666666666666666666666666666666666666666666666666666666


//CYCLE STAGES ++++++++++++++++++++++++++++++++++++++++++++++++++++++++++++++++++++++++++++++++++++++++++++++++++++++++++++++++++++

//Dynamic Neutral, stands still when modifiers are low
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

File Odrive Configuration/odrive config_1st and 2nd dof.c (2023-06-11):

// Factory reset Odrive
odrv0.erase_configuration()

//Check
odrv0.axis0.encoder.config.use_index_offset = True
odrv0.axis0.encoder.config.index_offset = 0

odrv0.axis1.encoder.config.use_index_offset = True
odrv0.axis1.encoder.config.index_offset = 0

//Motor Configuration for Turnigy 100 kV
odrv0.axis0.motor.config.motor_type = MOTOR_TYPE_HIGH_CURRENT
odrv0.axis0.motor.config.pole_pairs = 20
odrv0.axis0.motor.config.torque_constant = 8.27/100
odrv0.axis0.motor.config.calibration_current = 20

odrv0.axis1.motor.config.motor_type = MOTOR_TYPE_HIGH_CURRENT
odrv0.axis1.motor.config.pole_pairs = 20
odrv0.axis1.motor.config.torque_constant = 8.27/100
odrv0.axis1.motor.config.calibration_current = 20

odrv0.axis0.motor.config.current_lim = 40
odrv0.axis0.controller.config.vel_limit = 5

odrv0.axis1.motor.config.current_lim = 40
odrv0.axis1.controller.config.vel_limit = 5

//Encoder configuration for AS5047D
odrv0.axis0.encoder.config.mode = 0
odrv0.axis0.encoder.config.cpr = 2000
odrv0.axis0.encoder.config.use_index = False

odrv0.axis1.encoder.config.mode = 0
odrv0.axis1.encoder.config.cpr = 2000
odrv0.axis1.encoder.config.use_index = False

//SPI Mode
odrv0.axis0.encoder.config.abs_spi_cs_gpio_pin = 3
odrv0.axis1.encoder.config.abs_spi_cs_gpio_pin = 4
odrv0.axis0.encoder.config.mode = ENCODER_MODE_SPI_ABS_AMS
odrv0.axis1.encoder.config.mode = ENCODER_MODE_SPI_ABS_AMS
odrv0.axis0.encoder.config.cpr = 2**14
odrv0.axis1.encoder.config.cpr = 2**14

//Startup configuration
//odrv0.axis0.config.startup_encoder_offset_calibration = True
odrv0.axis0.config.startup_closed_loop_control = False
odrv0.axis1.config.startup_closed_loop_control = False

odrv0.axis0.config.startup_encoder_index_search = False
odrv0.axis1.config.startup_encoder_index_search = False

//General configuration
odrv0.config.enable_brake_resistor = True
odrv0.config.brake_resistance = 2
odrv0.config.dc_bus_overvoltage_trip_level = 25

//Tuning
odrv0.axis0.controller.config.pos_gain = 100
odrv0.axis0.controller.config.vel_gain = 0.3
odrv0.axis0.controller.config.vel_integrator_gain = 0.4

odrv0.axis1.controller.config.pos_gain = 100
odrv0.axis1.controller.config.vel_gain = 0.3
odrv0.axis1.controller.config.vel_integrator_gain = 0.4

odrv0.axis0.trap_traj.config.vel_limit = 5.0
odrv0.axis0.trap_traj.config.accel_limit = 5.0
odrv0.axis0.trap_traj.config.decel_limit = 5.0

odrv0.axis1.trap_traj.config.vel_limit = 5.0
odrv0.axis1.trap_traj.config.accel_limit = 5.0
odrv0.axis1.trap_traj.config.decel_limit = 5.0

//Save and reboot
odrv0.save_configuration()
odrv0.reboot()


//Run encoder offset calibration
odrv0.axis0.requested_state = 3
odrv0.axis1.requested_state = 3

odrv0.axis0.requested_state = AXIS_STATE_CLOSED_LOOP_CONTROL
odrv0.axis1.requested_state = AXIS_STATE_CLOSED_LOOP_CONTROL

odrv0.axis0.encoder.set_linear_count(0)
odrv0.axis1.encoder.set_linear_count(0)

odrv0.axis0.encoder.config.pre_calibrated = True
odrv0.axis1.encoder.config.pre_calibrated = True

odrv0.axis0.motor.config.pre_calibrated = True
odrv0.axis1.motor.config.pre_calibrated = True

odrv0.axis0.controller.input_pos = 4*35/360
odrv0.axis1.controller.input_pos = -4*35/360

odrv0.axis0.controller.input_pos = 0
odrv0.axis1.controller.input_pos = 0


odrv0.axis0.requested_state = 1
odrv0.axis1.requested_state = 1

odrv0.axis0.encoder.pos_estimate
odrv0.axis1.encoder.pos_estimate

odrv0.axis0.controller.config.control_mode = CONTROL_MODE_VELOCITY_CONTROL
odrv0.axis0.controller.input_vel = 0.2

odrv0.axis1.controller.config.control_mode = CONTROL_MODE_VELOCITY_CONTROL
odrv0.axis1.controller.input_vel = 0.2


odrv0.axis0.controller.config.input_mode = INPUT_MODE_TRAP_TRAJ
odrv0.axis1.controller.config.input_mode = INPUT_MODE_TRAP_TRAJ

//Check for motor error before setting pre_calibration
odrv0.axis0.motor.error


//Position control
odrv0.axis0.controller.config.control_mode = CONTROL_MODE_POSITION_CONTROL
odrv0.axis0.controller.input_pos


//Anti cogging Algorithm

//Start the calibration
odrv0.axis0.controller.start_anticogging_calibration()
odrv0.axis1.controller.start_anticogging_calibration()

//Put the gain back to what it was before
//odrv0.axis0.controller.config.vel_integrator_gain  = (0.5 * 10 * 0.32/2 )  //0.30
//odrv0.axis0.controller.config.pos_gain = 15 //100

// Wait until odrv0.axis0.controller.config.anticogging.calib_anticogging == False
// you can type 
odrv0.axis0.controller.config.anticogging.calib_anticogging
odrv0.axis1.controller.config.anticogging.calib_anticogging
// and just up arrow and enter till it turns false

//After the calibration is completed
odrv0.axis0.controller.config.anticogging.pre_calibrated = True
odrv0.axis1.controller.config.anticogging.pre_calibrated = True

odrv0.save_configuration()
odrv0.reboot()

//Set Linear Count with gear engaged
odrv0.axis0.encoder.set_linear_count(0)
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

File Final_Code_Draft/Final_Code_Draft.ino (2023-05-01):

#include <math.h>
#include <HardwareSerial.h>
#include <SoftwareSerial.h>
#include <ODriveArduino.h>
#include <Ramp.h>
#include <SerialTransfer.h>
#include <DFRobot_RGBLCD1602.h>
#include "structdef.h"

// Printing with stream operator helper functions
template<class T> inline Print& operator <<(Print &obj,     T arg) { obj.print(arg);    return obj; }
template<>        inline Print& operator <<(Print &obj, float arg) { obj.print(arg, 4); return obj; }

HardwareSerial& odrive_serial1 = Serial1;
HardwareSerial& odrive_serial2 = Serial2;
HardwareSerial& odrive_serial3 = Serial3;
HardwareSerial& BT_serial = Serial4;
HardwareSerial& odrive_serial4 = Serial5; 
HardwareSerial& odrive_serial5 = Serial6;
HardwareSerial& odrive_serial6 = Serial7;

//Arrays: [iterations][legs][x,y,z coordinates]
//$$$$$$$$$$$$$$$$$[Leg 1 : FR, Leg 2: BL, Leg 3: BR, Leg 4:FL]$$$$$$$$$$$$$$$$$$$$$$$$$$//

// ODrive object
ODriveArduino odrive1(odrive_serial1);  // Leg 1 FR
ODriveArduino odrive2(odrive_serial2);  // Shoulder front
ODriveArduino odrive3(odrive_serial3);  // Leg 4 FL
ODriveArduino odrive4(odrive_serial4);  // Leg 3 BR
ODriveArduino odrive5(odrive_serial5);  // Shoulder back
ODriveArduino odrive6(odrive_serial6);  // Leg 2 BL

//Bluetooth Serial
//SoftwareSerial BT_serial(10, 11);
SerialTransfer receive_packet;

//LCD
DFRobot_RGBLCD1602 lcd(16,2);

float leglen = 140.0;
float feetlen = 10;
float LRrat;
float FBrat;
float RTrat;

int xx=100;
int yy=100;
int zz=100;
int stepd;
int numm;
int citr;
int itrflag;
int closedloopflag;
int mode;
int modeflag;
int offsetflag;
int homeflag;

long btmillis;
unsigned long currentmillis;
unsigned long prevmillis;
unsigned long homemillis;
unsigned long crawlmillis;

double *phi = (double *) malloc(sizeof(double)*3);
double interpout [legn][coor];
double inipos[legn][coor];
double intermpos[legn][coor];
double mat[legn][coor];
double invmat[legn][coor];

//Gait Initialisation  -  Copy gait matrix from GUI
gait_struct crawl;
gait2_struct trot;

//Function Prototypes
void state(int x);
float thresholdfilter(float inp);
void pos_est(double pos[legn][coor]);
//void drive(int legnum,double* p,float a,float b,float c);
//void kinematics_3d(double x, double y, double z, double *p);
void create_mat(double q[4][3],gait_struct *gait,float a,float b,float c,int iter);
void kinematics_mat(double inp[legn][coor], double out[legn][coor],double pos[legn][coor]);
void actuate(double inp[legn][coor]);

class Interpolation{
  public:
  rampDouble myRamp;
  int interpolationFlag = 0;
  double savedValue;

  double go_dbl(double input, int duration) {

   if (input != savedValue) {   // check for new data
     interpolationFlag = 0;
   }
     savedValue = input;          // bookmark the old value

   if (interpolationFlag == 0) {                                        // only do it once until the flag is reset
     myRamp.go(input, duration, LINEAR, ONCEFORWARD);              // start interpolation (value to go to, duration)
     interpolationFlag = 1;
    }

   double output = myRamp.update();
   return output;
}
};

Interpolation interp[legn][coor];

/*double mapf(long x, long in_min, long in_max, float out_min, float out_max)
{
  return double((x - in_min) * (out_max - out_min) / (in_max - in_min) + out_min);
};*/

void setup() {
  Serial.begin(115200);
  Serial1.begin(115200);
  Serial2.begin(115200);
  Serial3.begin(115200);
  Serial5.begin(115200);
  Serial6.begin(115200);
  Serial7.begin(115200);
  BT_serial.begin(9600); //baud rate for software serial (bluetooth serial)
  receive_packet.begin(BT_serial); //setting serial transfer object to bluetooth
//
  lcd.init(); //initialising LCD and starting I2C bus
  lcd.setRGB(0, 0, 255); //r g b color brightness we only can use b
  
  int num_itr = sizeof(crawl)/sizeof(double)/legn/coor/3;
  int itrcount=0;

  //Obtain initial pos estimate from encoders
  pos_est(inipos);
  for(int ii=0;ii<legn;ii++){
        for(int jj=0;jj<coor;jj++){
          Serial<<"inipos["<<ii<<"]["<<jj<<"] = "<<inipos[ii][jj]<<'\t';
          if(inipos[ii][jj] == 0){
            lcd.setCursor(1,0);
            lcd.print("Offset error");
            offsetflag = 1;
          }
        }
        Serial.print('\n');
    }
  if(offsetflag!= 1){
    lcd.setCursor(0, 0); //row 1 col 1
    lcd.print("MQRPII is ready");
  }
}

void loop() {
  currentmillis = millis();
  
  if (receive_packet.available()){  //Check BT connection is established)
   receive_packet.rxObj(packet);
   btmillis = currentmillis;
   lcd.setCursor(0, 0);
   lcd.print("BlueT connected ");
   LRrat = thresholdfilter(packet.item1);
   FBrat = thresholdfilter(packet.item2);
   RTrat = thresholdfilter(packet.item3);
   Serial.println(LRrat);
   Serial.println(FBrat);
   Serial.println(RTrat);
   Serial.println(packet.item5);
   Serial.println(packet.item6);
   Serial.println(packet.item7);
   Serial.println(packet.item8);
//   Serial.println(packet.item9);
//   Serial.println(packet.item10);
  }

  if(currentmillis-btmillis > 2000){
    //state(1); //All odrives enter IDLE state 
//    LRrat = 0;
//    FBrat = 0;
//    RTrat = 0;
    lcd.setCursor(0, 0);
    lcd.print("BlueT disconnected");
// 
  }

  if(closedloopflag==0 && packet.item5 == 2){
    state(8); //All odrives enter closed loop control
    closedloopflag = 1;
    lcd.setCursor(0, 1);
    lcd.print("CLC ");
  }

  if(closedloopflag==1 && packet.item5 == 1){
    state(1); //All odrives enter IDLE state
    closedloopflag = 0;
    lcd.setCursor(0, 1);
    lcd.print("IDLE");
  }

  if(closedloopflag == 1 && packet.item7 == 1){
    mode = 1;
    prevmillis = millis();
    modeflag = 1;
    homeflag = 0;
  }
  if(closedloopflag == 0 && packet.item7 == 1){
    lcd.setCursor(0, 1);
    lcd.print("IDLE");
  }
  if(modeflag == 1 && packet.item6 == 1){
    mode = 0;
    homeflag = 1;
    lcd.setCursor(10, 1);
    lcd.print("     ");
    modeflag = 0;
    citr = 0;
    homemillis = millis();
    }
  if(homeflag == 1 && currentmillis-homemillis<1.5*timer){
    for(int ii=0;ii<legn;ii++){
      for(int jj=0;jj<coor;jj++){
        interpout[ii][jj] = interp[ii][jj].go_dbl(inipos[ii][jj],timer);
          Serial.print(interpout[ii][jj]);Serial.print('\t');
    }
        Serial.print('\n');
    }
    actuate(interpout);
  }
  if(mode == 1 && closedloopflag ==1){
    lcd.setCursor(10, 1);
    lcd.print("CRAWL");
    create_mat(mat,&crawl,FBrat,LRrat,0,citr);
//  create_mat(mat,&crawl,0.5,0.5,0,citr);
//  for(int ii=0;ii<legn;ii++){
//      for(int jj=0;jj<coor;jj++){
//        Serial.print(mat[ii][jj]);
//        Serial.print('\t');  
//      }
//      Serial.print('\n');
//  }
    for(int ii=0;ii<legn;ii++){
        for(int jj=0;jj<coor;jj++){
          interpout[ii][jj] = interp[ii][jj].go_dbl(mat[ii][jj],timer);
//          Serial.print(interpout[ii][jj]);Serial.print('\t');
        }
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

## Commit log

2023-02-28 Uploading IMU arduino file
    Utilises I2C
    Adapted from LS9DS1 example
    complimentary filter is implemented, but low-pass filter needs debugging
2023-02-28 Fixed_complimentary_filter
    Forgot to iterate phiHat and thetaHat to the new calculted estimate
    Code now runs as expected.
    Some pros and cons:
    Pro:
    1) Noise is heavily attenuated
    2) External force affecting angle reading is heavily attenuated
    con:
    1) There is delay between real time reading and reading convergence when using the filter
    [IMU_SKETCH.ino]
2023-02-28 defined alpha variable
    defined the variable alpha for complimentary filter
2023-03-17 Added Bluetooth+SerialTransfer
    1) Bluetooth Master set up for controller-side Arduino.
    2) SerialTransfer set up to be able to stuff packet with struct (transmit side of arduino) and send to teensy
2023-03-24 cleaned up and commented imu code
2023-04-05 Resolved issues with merging and adding the extra buttons
    [Bluetooth_test_slave_joysticks.ino, CONTROLLER_SKETCH_joysticks.ino]
2023-05-02 Update IMU_SKETCH.ino
    Added offset calculations for
    Front right
    Front left
    Rear right
    Rear left
    based on IMU readings.
    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
2023-05-07 Main STLs and DXFs
    raw STLs and DXFs utilised in the final robot.
    [2X Middle Plate.dxf, 2X Shaft Brace Bearing Mount.stl, Acrylic Mount.stl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]
2023-06-10 Added Design files
    .DXF files for laser cutting and .STLs for 3D printing.
2023-06-11 Added circuit diagrams
